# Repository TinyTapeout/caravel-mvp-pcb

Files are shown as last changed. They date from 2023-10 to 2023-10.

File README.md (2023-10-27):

# Caravel MVP

This is a sample "minimum viable PCB" for [Caravel chips](https://caravel-harness.readthedocs.io/en/latest/): Google MPW or [chipIgnite](https://info.efabless.com/chipignite-v2), including variants for [TinyTapeout](https://tinytapeout.com/).

Fork this repo to get a head start on spinning your own Caravel based PCB.

The circuit includes all the critical (required) elements, basically:

  * power regulation;
  * a clock signal;
  * flash memory, for code; and
  * the chip itself

along with basic passive support (bypass caps...) [Full schematic PDF here](doc/caravel-mvp.pdf)

It also has a few switches and connectors, as demonstrations.  These are enclosed in dotted boxes to highlight their optionality.

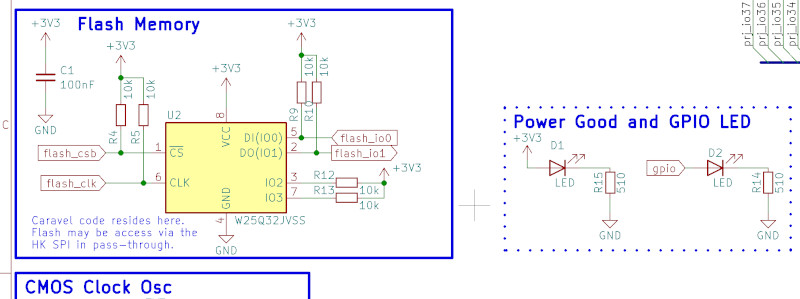
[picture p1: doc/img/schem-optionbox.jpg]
Option Box


The full schematic is available as a PDF in the doc/ directory.

A sample layout was also included, though routing was not completed as you're certainly going to want to change components and floorplan around for your custom boards.

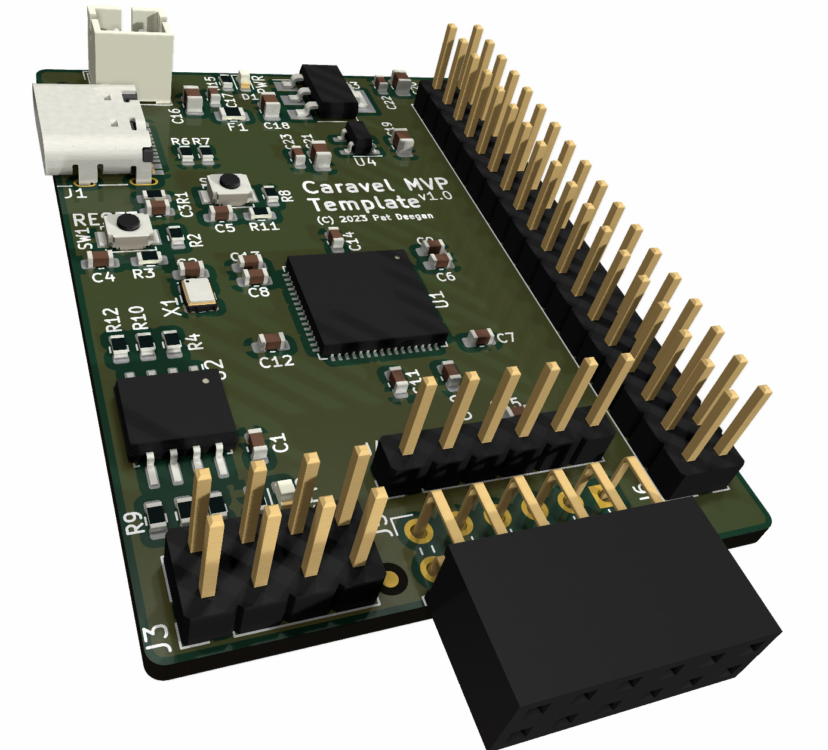
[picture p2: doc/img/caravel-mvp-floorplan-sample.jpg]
PCB Floorplan


# Footprints and Symbols

Useful symbols and footprints are used here and elsewhere, included as a submodule.

```
  git submodule update --init --recursive
```
will actually brings these in to your local fs.

# TinyTapeout

A TinyTapeout-specific versions are also included. If using along with the Caravel CPU, the only real differences are in the symbol and net names used, as this helps to clarify things a lot.

However, you may also use it stand-alone, in which case a few components aren't required (e.g. flash memory) and a few additional ones are needed (mainly passives for pull-ups and config bootstraps).

If you are implementing a PCB for a TinyTapeout chip, simply:

```
  git checkout tt123
```

and the schematic ([TT version PDF here](doc/caravel-mvp-tinytapeout.pdf)) will include something like this instead:

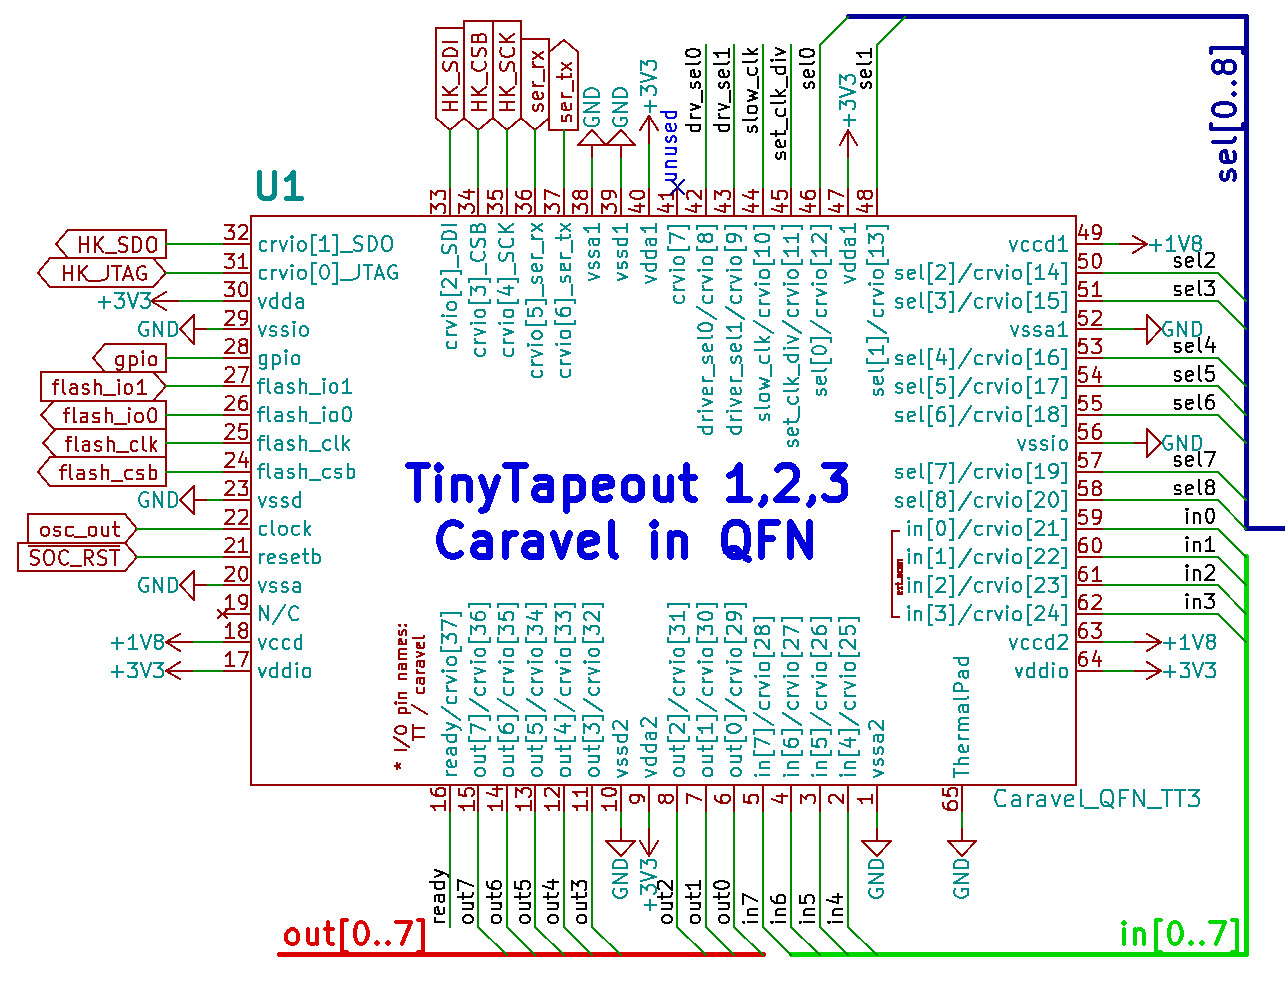
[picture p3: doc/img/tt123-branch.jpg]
TT123 branch


along with the TT standalone config sheet.

# Resources

### TinyTapeout
[TinyTapeout](https://tinytapeout.com/) is an educational project that makes it easier and cheaper than ever to get your digital designs manufactured on a real chip.

It's the easiest and cheapest way I know to get your designs on an ASIC.

### Caravel

Caravel is composed of a harness frame plus two wrappers for drop-in modules for the management area and user project area.  Basically a SoC with a RISC-V CPU, space for user designs and ways to connect those to the outside world.

See:
 * [Caravel chips](https://caravel-harness.readthedocs.io/en/latest/)
 * [efabless/caravel](https://github.com/efabless/caravel)
 * [efabless/caravel_mgmt_soc_litex](https://github.com/efabless/caravel_mgmt_soc_litex)

# License

This is meant as a template and starting point for your own projects and is all released under as open hardware.  The MVP schematics and layouts are

  Copyright (C) 2023 Pat Deegan, [Psychogenic Technologies](https://psychogenic.com)

and released under the terms of the Apache License, version 2.0.  See the accompanying LICENSE file for details.

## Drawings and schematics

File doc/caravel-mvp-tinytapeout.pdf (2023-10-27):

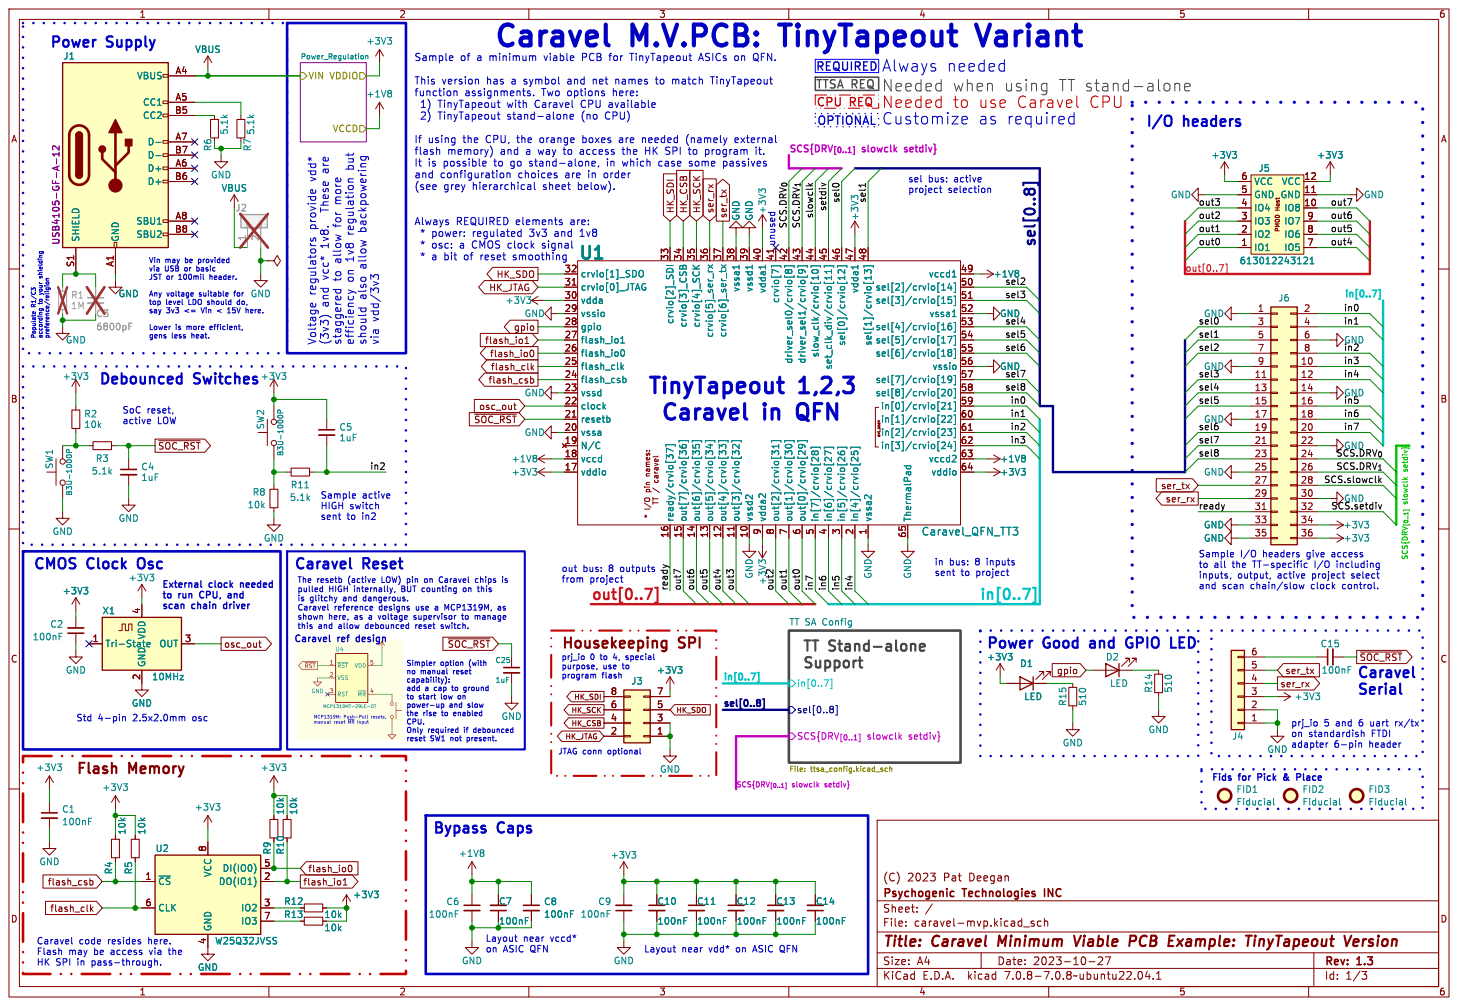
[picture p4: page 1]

Caravel M.V.PCB: TinyTapeout Variant

Power_Regulation
VIN
TTSA REQ Voltage regulators provide vdd* (3v3) and vcc* 1v8. These are staggered to allow for more efficiency on 1v8 regulation but should also allow backpowering via vdd/3v3

Always needed
Needed when using TT stand-alone

If using the CPU, the orange boxes are needed (namely external flash memory) and a way to access the HK SPI to program it.

* osc: a CMOS clock signal * a bit of reset smoothing

Vin may be provided
via USB or basic

* I/O pin names: TT / caravel ext_scan vssa2

1 vssd2 10 out[3]/crvio[32] 11 out[4]/crvio[33] 12 out[5]/crvio[34] 13 out[6]/crvio[35] 14 out[7]/crvio[36] 15 ready/crvio[37] 16

Sample active HIGH switch

Sample I/O headers give access

reset SW1 not present. CMOS Clock Osc

sel[0..8] TT SA Config
TT Stand-alone
Support

Power Good and GPIO LED

prj_io 0 to 4, special purpose, use to

no manual reset capability): add a cap to ground

to start low on

Fids for Pick & Place

Layout near vccd* on ASIC QFN

Id: 1/3 Title: Caravel Minimum Viable PCB Example: TinyTapeout Version

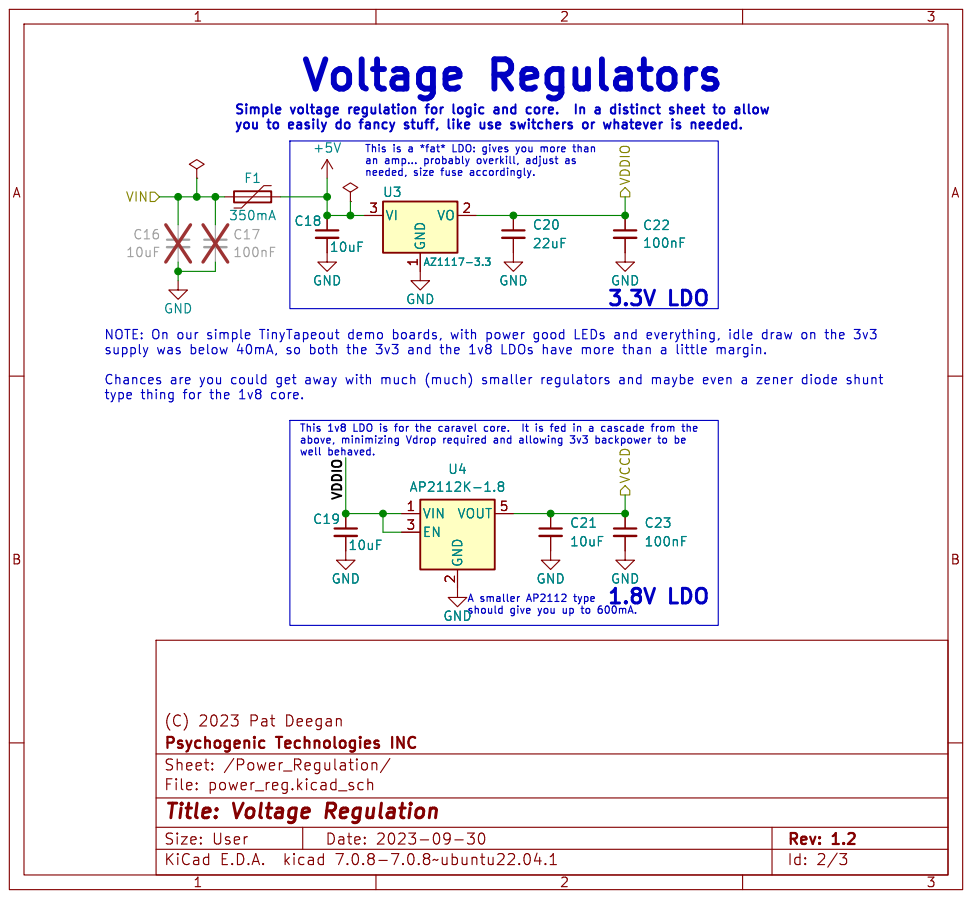
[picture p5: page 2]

1 VO 2 VI 3 GND GND

Id: 2/3 Title: Voltage Regulation

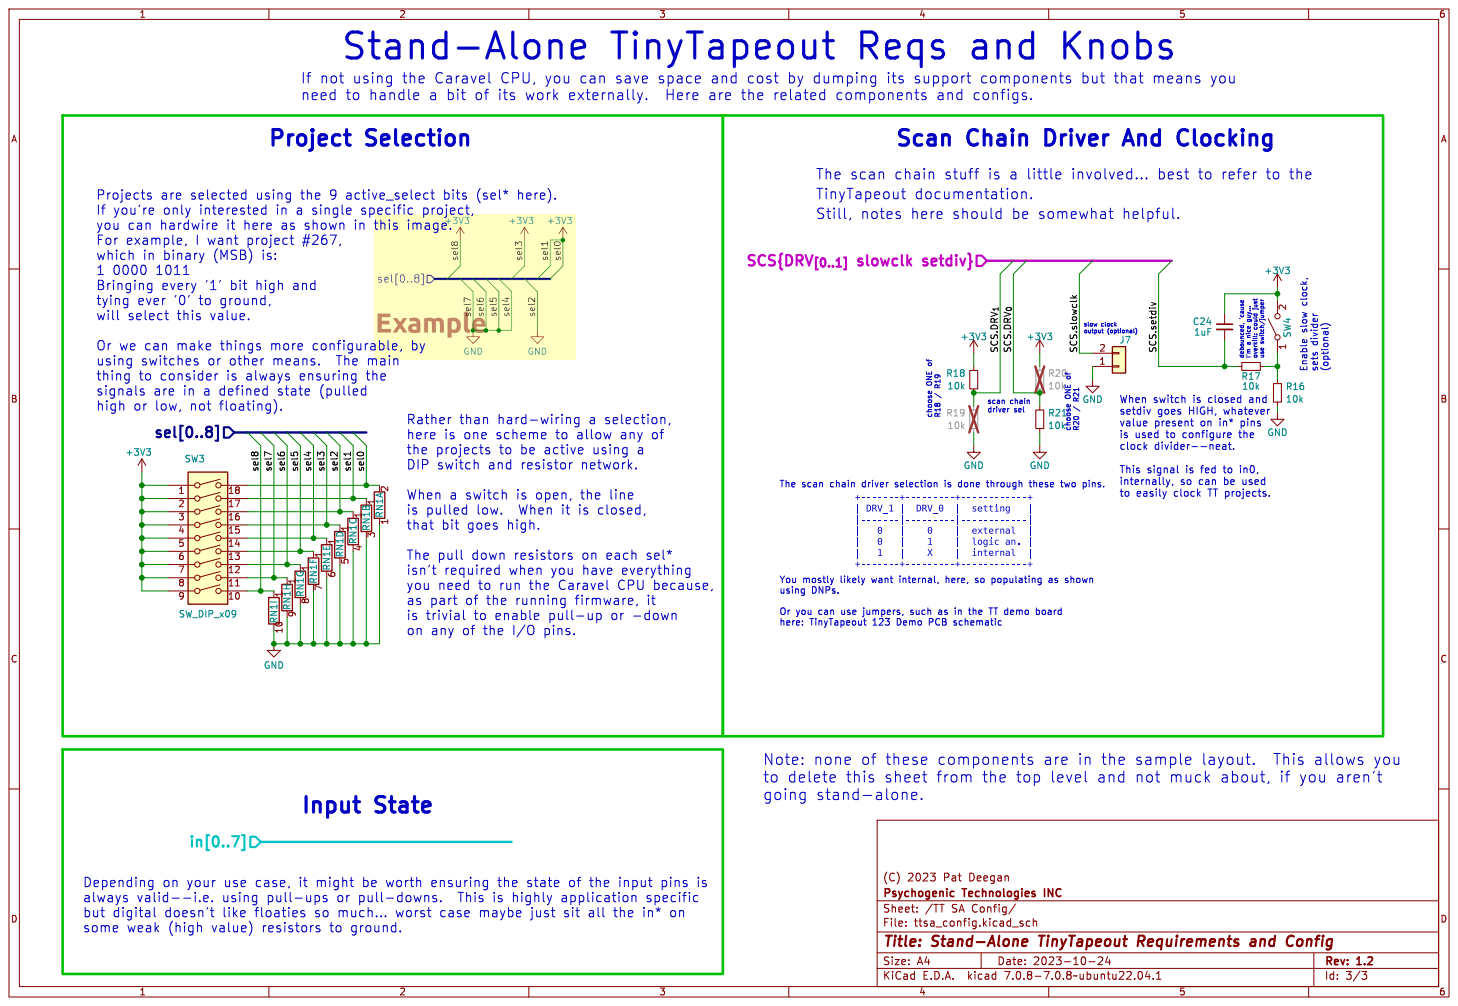
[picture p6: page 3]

here: TinyTapeout 123 Demo PCB schematic (https://github.com/TinyTapeout/tt123-demo-pcb/blob/main/doc/mpw-mb1-v2-2-2.pdf) Scan Chain Driver And Clocking

TinyTapeout documentation. (https://github.com/tinytapeout/tinytapeout-mpw7/blob/mpw7/INFO.md) +-------+---------+------------+
Still, notes here should be somewhat helpful.

you can hardwire it here as shown in this image.
For example, I want project #267,
which in binary (MSB) is:
Bringing every '1' bit high and
tying ever '0' to ground,
will select this value.

to easily clock TT projects. debounced, 'cause I'm a nice guy... overkill: could just use switch/jumper

thing to consider is always ensuring the
signals are in a defined state (pulled
high or low, not floating).
9SW3 SW_DIP_x09

here is one scheme to allow any of
the projects to be active using a DIP switch and resistor network.

setdiv goes HIGH, whatever value present on in* pins

clock divider--neat. This signal is fed to in0,

When a switch is open, the line
that bit goes high.

isn't required when you have everything

on any of the I/O pins.

to delete this sheet from the top level and not muck about, if you aren't

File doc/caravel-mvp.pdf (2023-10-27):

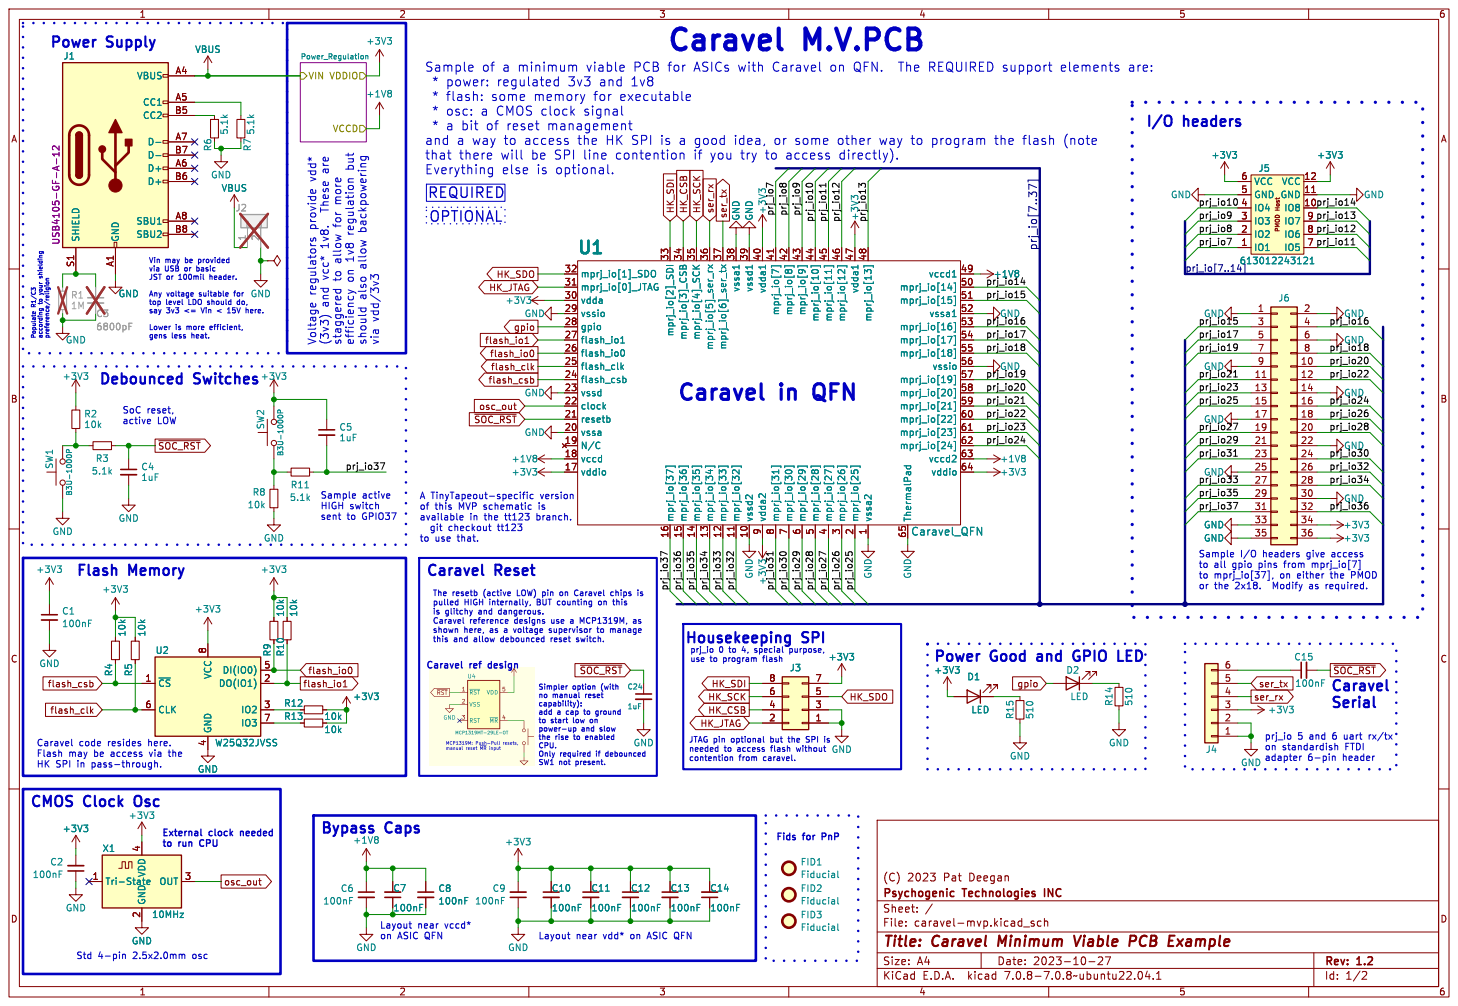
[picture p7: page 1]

* flash: some memory for executable
* osc: a CMOS clock signal * a bit of reset management

and a way to access the HK SPI is a good idea, or some other way to program the flash (note
Everything else is optional.
REQUIRED

SoC reset, active LOW

to use that. Caravel ref design

GND
Sample I/O headers give access
to all gpio pins from mprj_io[7]

Power Good and GPIO LED

no manual reset capability): add a cap to ground

to start low on

Layout near vdd* on ASIC QFN CMOS Clock Osc

Id: 1/2 Title: Caravel Minimum Viable PCB Example

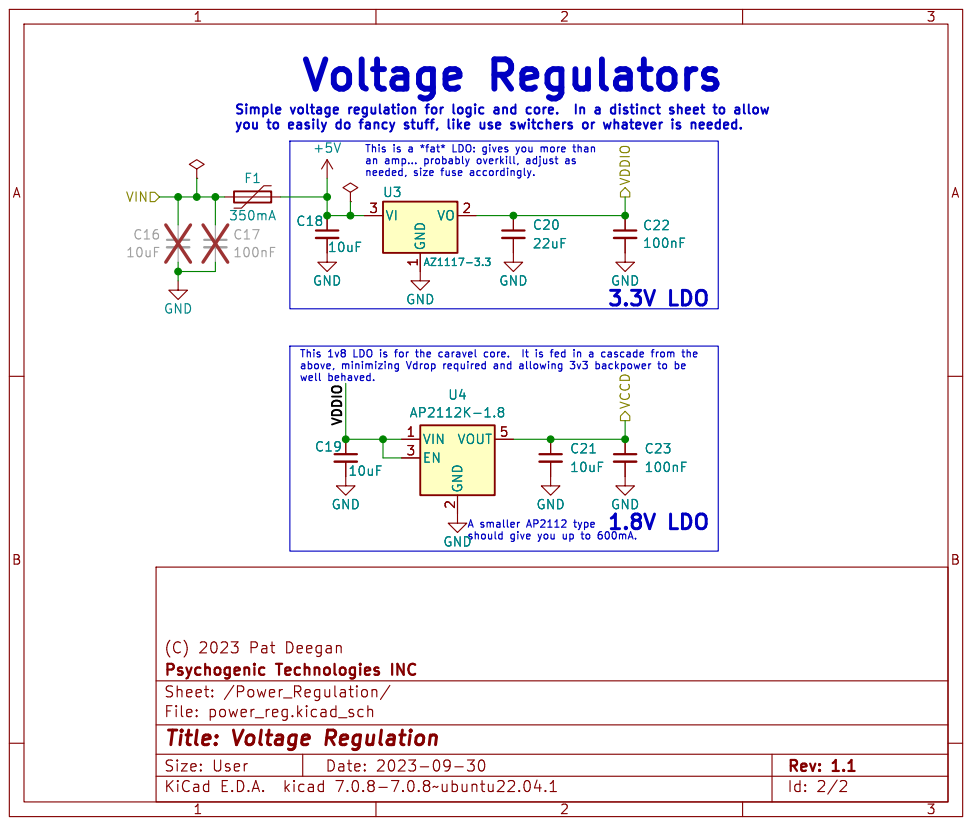
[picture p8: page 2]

you to easily do fancy stuff, like use switchers or whatever is needed. Voltage Regulators

1 VO 2 VI 3 GND GND GND

Id: 2/2 Title: Voltage Regulation

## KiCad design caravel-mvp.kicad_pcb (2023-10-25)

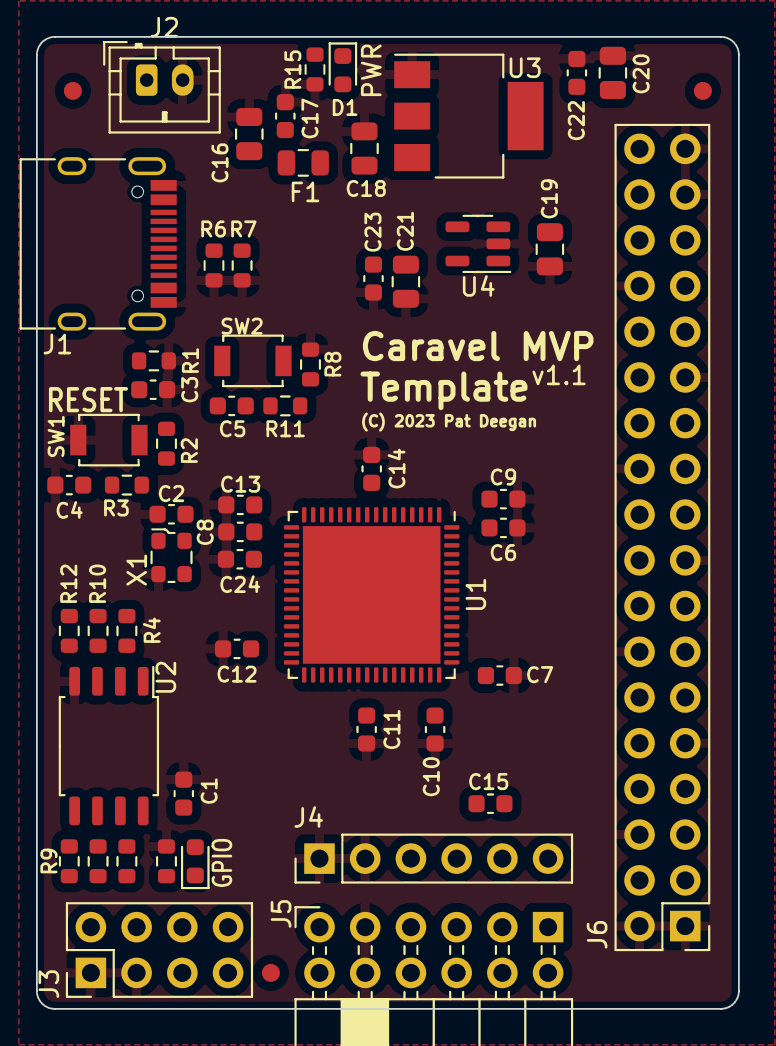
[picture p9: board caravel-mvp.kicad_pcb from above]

Board: 4 copper layers, 39.0 x 54.0 mm, 58 parts (0 on the bottom side), 60 nets, no tracks yet.

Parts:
C1, C2, C6, C7, C8, C9, C10, C11, C12, C13, C14, C15, C17, C22, C23: 100nF; C_0603_1608Metric
C3: 6800pF; C_0603_1608Metric
C4, C5, C24: 1uF; C_0603_1608Metric
C16, C18, C19, C21: 10uF; C_0805_2012Metric
C20: 22uF; C_0805_2012Metric
D1, D2: LED; LED_0603_1608Metric
F1: 350mA; Fuse_0805_2012Metric
FID1, FID2, FID3: Fiducial; Fiducial_1mm_Mask2mm
J1: USB_C_Receptacle_USB2.0; USB_C_Receptacle_HRO_TYPE-C-31-M-12
J2: Conn_01x02; JST_PH_B2B-PH-K_1x02_P2.00mm_Vertical
J3: Conn_02x04_Odd_Even; PinHeader_2x04_P2.54mm_Vertical
J4: Conn_01x06; PinHeader_1x06_P2.54mm_Vertical
J5: 613012243121; PinSocket_2x06_P2.54mm_PMODHost1A
J6: Conn_02x18_Odd_Even; PinHeader_2x18_P2.54mm_Vertical
R1: 1M; R_0603_1608Metric
R2, R4, R5, R8, R9, R10, R12, R13: 10k; R_0603_1608Metric
R3, R6, R7, R11: 5.1k; R_0603_1608Metric
R14, R15: 510; R_0603_1608Metric
SW1, SW2: B3U-1000P; SW_SPST_B3U-1000P
U1: Caravel_QFN; QFN-64-1EP_9x9mm_P0.5mm_EP7.65x7.65mm
U2: W25Q32JVSS; SOIC-8_5.23x5.23mm_P1.27mm
U3: AZ1117-3.3; SOT-223-3_TabPin2
U4: AP2112K-1.8; SOT-23-5
X1: 10MHz; Oscillator_SMD_ECS_2520MV-xxx-xx-4Pin_2.5x2.0mm

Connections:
+1V8: C6.1, C7.2, C8.1, C21.1, C23.1, U1.18 (vccd), U1.49 (vccd1), U1.63 (vccd2), U4.5 (VOUT)
+3V3: C1.1, C2.2, C5.1, C9.2, C10.1, C11.1, C12.1, C13.1, C14.2, C19.1, C20.1, C22.1, D1.2 (A), J3.7, J4.3, J5.6 (VCC), J5.12 (VCC), J6.34, J6.36, R2.1, R4.1, R5.1, R9.1, R10.1, R12.2, R13.2, SW2.2, U1.9 (vdda2), U1.17 (vddio), U1.30 (vdda), U1.40 (vdda1), U1.47 (vdda1), U1.64 (vddio), U2.8 (VCC), U3.2 (VO), U4.1 (VIN), U4.3 (EN), X1.4 (VDD)
+5V: C18.1, F1.2, U3.3 (VI)
/prj_io7: J5.1 (IO1), U1.41 (mprj_io[7])
/prj_io8: J5.2 (IO2), U1.42 (mprj_io[8])
/prj_io9: J5.3 (IO3), U1.43 (mprj_io[9])
/prj_io10: J5.4 (IO4), U1.44 (mprj_io[10])
/prj_io11: J5.7 (IO5), U1.45 (mprj_io[11])
/prj_io12: J5.8 (IO6), U1.46 (mprj_io[12])
/prj_io13: J5.9 (IO7), U1.48 (mprj_io[13])
/prj_io14: J5.10 (IO8), U1.50 (mprj_io[14])
/prj_io15: J6.3, U1.51 (mprj_io[15])
/prj_io16: J6.4, U1.53 (mprj_io[16])
/prj_io17: J6.5, U1.54 (mprj_io[17])
/prj_io18: J6.8, U1.55 (mprj_io[18])
/prj_io19: J6.7, U1.57 (mprj_io[19])
/prj_io20: J6.10, U1.58 (mprj_io[20])
/prj_io21: J6.11, U1.59 (mprj_io[21])
/prj_io22: J6.12, U1.60 (mprj_io[22])
/prj_io23: J6.13, U1.61 (mprj_io[23])
/prj_io24: J6.16, U1.62 (mprj_io[24])
/prj_io25: J6.15, U1.2 (mprj_io[25])
/prj_io26: J6.18, U1.3 (mprj_io[26])
/prj_io27: J6.19, U1.4 (mprj_io[27])
/prj_io28: J6.20, U1.5 (mprj_io[28])
/prj_io29: J6.21, U1.6 (mprj_io[29])
/prj_io30: J6.24, U1.7 (mprj_io[30])
/prj_io31: J6.23, U1.8 (mprj_io[31])
/prj_io32: J6.26, U1.11 (mprj_io[32])
/prj_io33: J6.27, U1.12 (mprj_io[33])
/prj_io34: J6.28, U1.13 (mprj_io[34])
/prj_io35: J6.29, U1.14 (mprj_io[35])
/prj_io36: J6.32, U1.15 (mprj_io[36])
/prj_io37: C5.2, J6.31, R11.2, U1.16 (mprj_io[37])
GND: C1.2, C2.1, C3.2, C4.2, C6.2, C7.1, C8.2, C9.1, C10.2, C11.2, C12.2, C13.2, C14.1, C16.2, C17.2, C18.2, C19.2, C20.2, C21.2, C22.2, C23.2, C24.2, J1.A1 (GND), J1.A12 (GND), J1.B1 (GND), J1.B12 (GND), J2.2, J3.1, J3.3, J4.1, J4.2, J5.5 (GND), J5.11 (GND), J6.1, J6.2, J6.6, J6.9, J6.14, J6.17, J6.22, J6.25, J6.30, J6.33, J6.35, R1.2, R6.2, R7.2, R8.2, R14.2, R15.2, SW1.1, U1.1 (vssa2), U1.10 (vssd2), U1.20 (vssa), U1.23 (vssd), U1.29 (vssio), U1.38 (vssa1), U1.39 (vssd1), U1.52 (vssa1), U1.56 (vssio), U1.65 (ThermalPad), U2.4 (GND), U3.1 (GND), U4.2 (GND), X1.2 (GND)
HK_CSB: J3.4, U1.34 (mprj_io[3]_CSB)
HK_JTAG: J3.2, U1.31 (mprj_io[0]_JTAG)
HK_SCK: J3.6, U1.35 (mprj_io[4]_SCK)
HK_SDI: J3.8, U1.33 (mprj_io[2]_SDI)
HK_SDO: J3.5, U1.32 (mprj_io[1]_SDO)
unnamed: D1.1 (K), R15.1
unnamed: D2.1 (K), R14.1
unnamed: J1.A5 (CC1), R7.1
unnamed: J1.B5 (CC2), R6.1
unnamed: C3.1, J1.S1 (SHIELD), R1.1
unnamed: C15.1, J4.6
unnamed: R2.2, R3.1, SW1.2
unnamed: R8.1, R11.1, SW2.1
unnamed: R12.1, U2.3 (IO2)
unnamed: R13.1, U2.7 (IO3)
VBUS: C16.1, C17.1, F1.1, J1.A4 (VBUS), J1.A9 (VBUS), J1.B4 (VBUS), J1.B9 (VBUS), J2.1
flash_clk: R5.2, U1.25 (flash_clk), U2.6 (CLK)
flash_csb: R4.2, U1.24 (flash_csb), U2.1 (~CS)
flash_io0: R9.2, U1.26 (flash_io0), U2.5 (DI(IO0))
flash_io1: R10.2, U1.27 (flash_io1), U2.2 (DO(IO1))
gpio: D2.2 (A), U1.28 (gpio)
osc_out: U1.22 (clock), X1.3 (OUT)
ser_rx: J4.4, U1.36 (mprj_io[5]_ser_rx)
ser_tx: J4.5, U1.37 (mprj_io[6]_ser_tx)
~SOC_RST: C4.1, C15.2, C24.1, R3.2, U1.21 (resetb)

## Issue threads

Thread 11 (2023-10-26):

Flash always required

mattvenn, 2023-10-26:
Due to https://github.com/TinyTapeout/tinytapeout-02/issues/10
Flash will always be required, even for external scan chain mode.

psychogenic, 2023-10-27:
Ok, so there is *no way* to avoid booting up and doing caravel things?  Is this only for TT2 or TT3 as well?

mattvenn, 2023-10-27:
TT3 fixed this issue with this change: https://github.com/TinyTapeout/tinytapeout-03/blob/main/verilog/rtl/user_defines.v#L102

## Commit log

2023-10-24 Caravel MVPCB initial commit
    [caravel-mvp.kicad_pcb, caravel-mvp.kicad_sch, power_reg.kicad_sch]
2023-10-25 Reset risetime fix
    [caravel-mvp.kicad_pcb, caravel-mvp.kicad_sch]
2023-10-25 Updated PDF
    [caravel-mvp.kicad_sch, power_reg.kicad_sch]
2023-10-27 Comment clarifications
    [caravel-mvp.kicad_sch]
2023-10-27 Cleanups and even more clarifications in comments
    [caravel-mvp.kicad_sch, power_reg.kicad_sch]
